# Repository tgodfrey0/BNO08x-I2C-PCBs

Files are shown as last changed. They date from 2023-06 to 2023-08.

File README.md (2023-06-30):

# BNO085 Interface Boards (I2C)

This repository contains W.I.P. code and hardware designed for a 9DOF sensor module using a BNO085.

The [`hardware` folder](hardware/README.md) contains all KiCAD files for the board.

The [`firmware` folder](firmware/README.md) contains the files required to run the sensor.

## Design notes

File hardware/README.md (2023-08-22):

# Hardware

The PCB designs were created in KiCAD and the panels were made using KiKit.

The sensor board is designed to be as small as possible, for this reason some features of the BNO085 are no longer accessible.

## PCB Board Key

Some of the boards are keyed to give them a known orientation. 

Both keys was created from the insersection between the main PCB edge circle and another circle placed in the top right corner of the main circle's bounding box. They are outlined below in the relevant screenshots (the y-axis has been inverted in Geogebra to visually match the KiCAD coordinate system).

### v6

All v6 boards have the same key and same key location. This is a through-hole with a diameter of 1mm. The centre of the key hole is located in the top left corner of the board; -3.35mm from the centre of the board along the x-axis, -3.25mm from the centre of the board along the y-axis. For both board sizes the hole is located in the same place. (Remember the KiCAD y-axis is inverted, therefore the delta-y of -3.25 means the hole is above the centre of the board.) 

### v5

The v5 board design has no physical key, however orientation pads were added to the front and back silkscreen these are in the top-left, top-right and bottom-right corners and can be used to orientate the board.

### v3

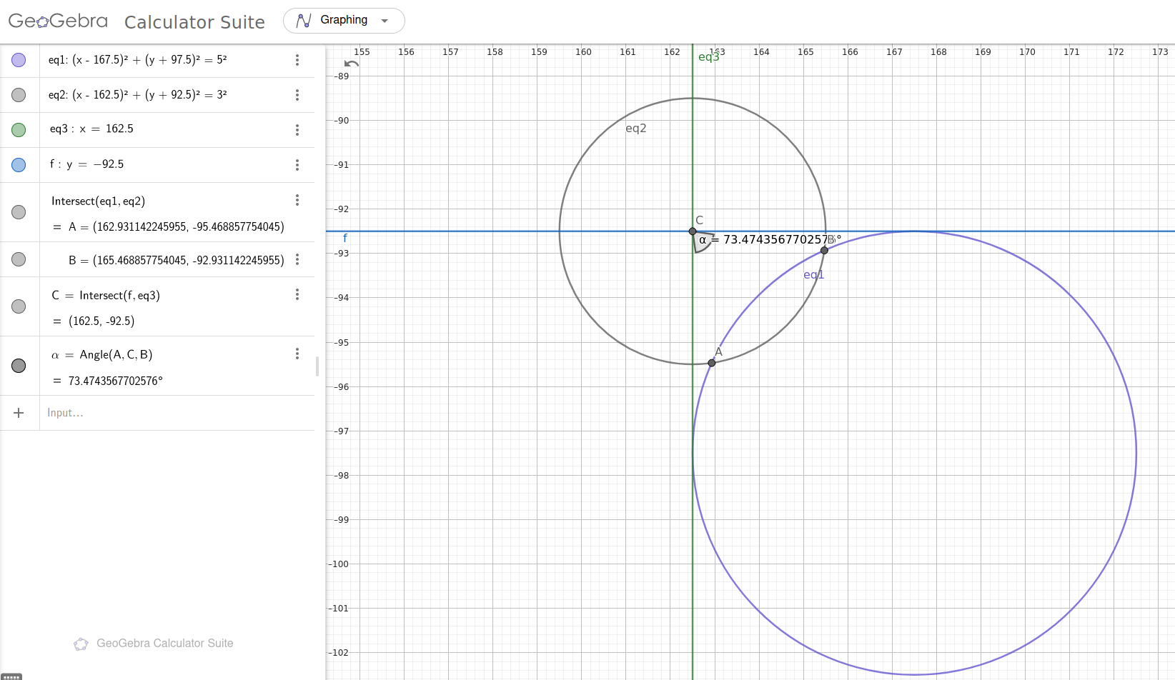
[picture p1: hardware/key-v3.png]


### v3-base

This board is the base for the `v3` panel. The difference is the flat spots by each pin to allow it to be panelised. This means the dimensions are slightly different.

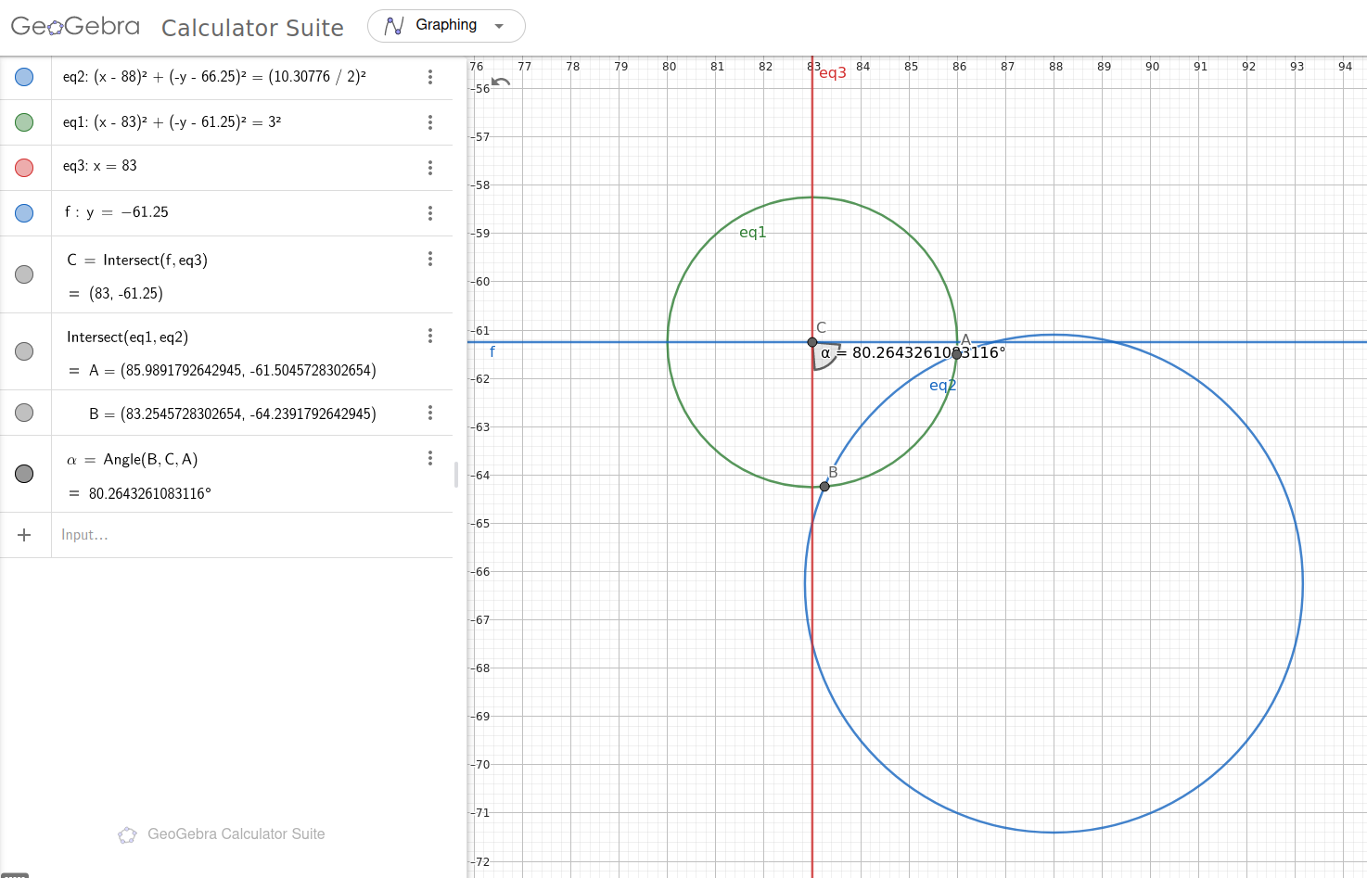
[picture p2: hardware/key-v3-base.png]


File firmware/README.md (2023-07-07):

# Firmware

The `adafruit-testing` folder contains very crude code used for I2C communication with an [Adafruit BNO085 breakout board](https://www.adafruit.com/product/4754#technical-details). This code is **not** intended to be used for project with the breakout board, it was used to check the minimum number of pins needed to communicate with the BNO085.

The `bno085-firmware` submodule contains the production code for the sensor. More info can be found [here](https://github.com/tgodfrey0/bno085-i2c-firmware).

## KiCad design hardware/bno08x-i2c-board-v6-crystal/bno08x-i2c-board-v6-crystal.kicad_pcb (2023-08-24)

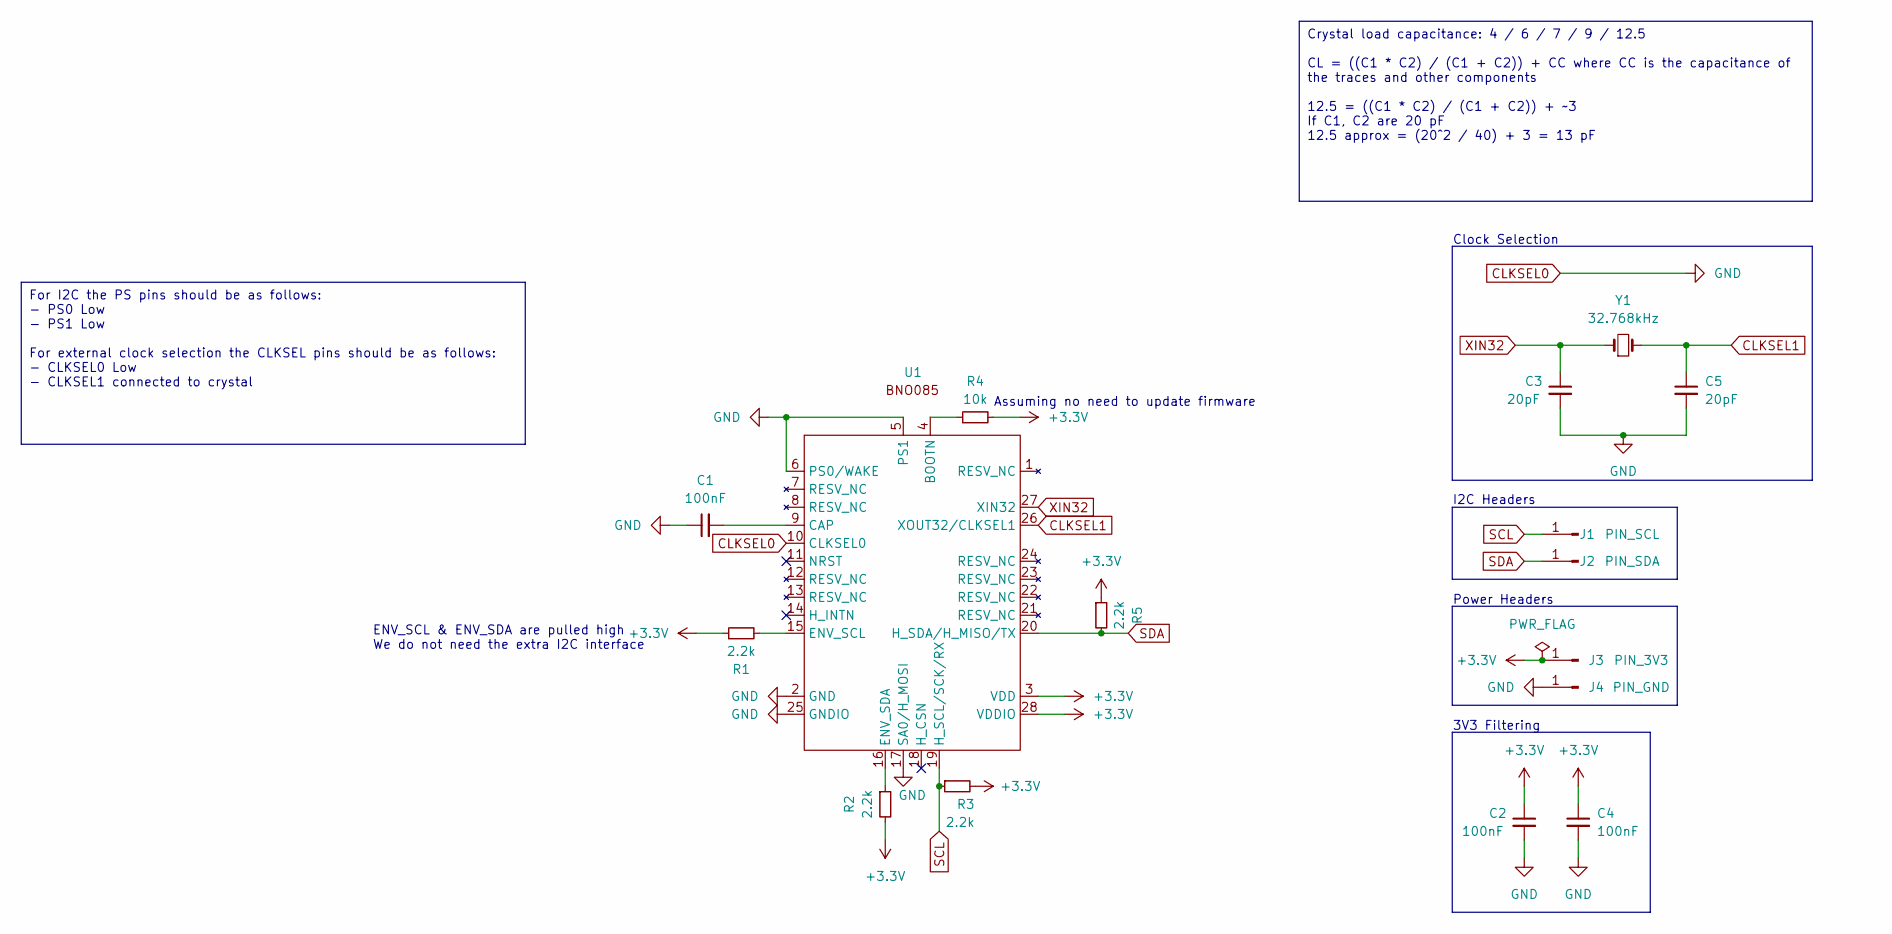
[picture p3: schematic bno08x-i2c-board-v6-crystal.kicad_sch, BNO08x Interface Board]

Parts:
C1, C2, C4: 100nF; C_0402_1005Metric
C3, C5: 20pF; C_0402_1005Metric
J1: PIN_SCL; PinHeader_1x01_P1.00mm_Vertical
J2: PIN_SDA; PinHeader_1x01_P1.00mm_Vertical
J3: PIN_3V3; PinHeader_1x01_P1.00mm_Vertical
J4: PIN_GND; PinHeader_1x01_P1.00mm_Vertical
R1, R2, R3, R5: 2.2k; R_0402_1005Metric
R4: 10k; R_0402_1005Metric
U1: LGA-28_5.2x3.8mm_P0.5mm
Y1: 32.768kHz; Crystal_SMD_MicroCrystal_CM9V-T1A-2Pin_1.6x1.0mm

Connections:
+3.3V: C2.1, C4.1, J3.1, R1.1, R2.2, R3.2, R4.2, R5.1, U1.3 (VDD), U1.28 (VDDIO)
CLKSEL0: C1.1, C2.2, C3.2, C4.2, C5.2, J4.1, U1.2 (GND), U1.5 (PS1), U1.6 (PS0/WAKE), U1.10 (CLKSEL0), U1.17 (SA0/H_MOSI), U1.25 (GNDIO)
CLKSEL1: C5.1, U1.26 (XOUT32/CLKSEL1), Y1.2
unnamed: R4.1, U1.4 (BOOTN)
unnamed: C1.2, U1.9 (CAP)
unnamed: R1.2, U1.15 (ENV_SCL)
unnamed: R2.1, U1.16 (ENV_SDA)
SCL: J1.1, R3.1, U1.19 (H_SCL/SCK/RX)
SDA: J2.1, R5.2, U1.20 (H_SDA/H_MISO/TX)
XIN32: C3.1, U1.27 (XIN32), Y1.1

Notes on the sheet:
Crystal load capacitance: 4 / 6 / 7 / 9 / 12.5 CL = ((C1 * C2) / (C1 + C2)) + CC where CC is the capacitance of the traces and other components 12.5 = ((C1 * C2) / (C1 + C2)) + ~3 If C1, C2 are 20 pF 12.5 approx = (20^2 / 40) + 3 = 13 pF
For I2C the PS pins should be as follows: - PS0 Low - PS1 Low For external clock selection the CLKSEL pins should be as follows: - CLKSEL0 Low - CLKSEL1 connected to crystal
3V3 Filtering
Assuming no need to update firmware
Clock Selection
I2C Headers
ENV_SCL & ENV_SDA are pulled high We do not need the extra I2C interface
Power Headers

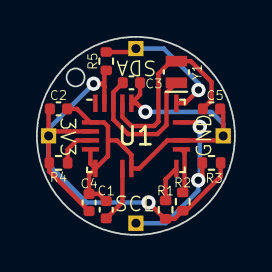
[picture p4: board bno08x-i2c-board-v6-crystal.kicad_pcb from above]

Board: 2 copper layers, 11.0 x 11.0 mm, 16 parts (0 on the bottom side), 10 nets.

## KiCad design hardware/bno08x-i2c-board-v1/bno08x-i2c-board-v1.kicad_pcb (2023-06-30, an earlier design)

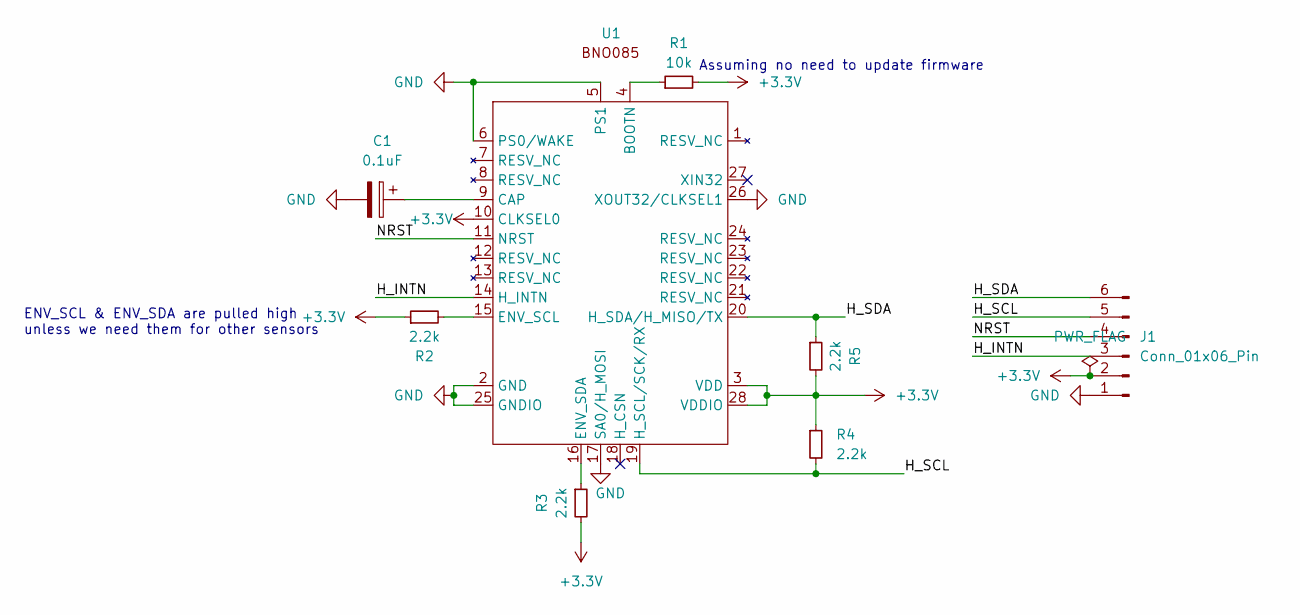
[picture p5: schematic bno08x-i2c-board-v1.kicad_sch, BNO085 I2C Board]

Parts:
C1: 0.1uF; CP_Elec_4x3.9
J1: Conn_01x06_Pin; PinHeader_1x06_P2.54mm_Horizontal
R1: 10k; R_0805_2012Metric
R2, R3, R4, R5: 2.2k; R_0805_2012Metric
U1: LGA-28_5.2x3.8mm_P0.5mm

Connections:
+3.3V: J1.2, R1.2, R2.1, R3.2, R4.1, R5.2, U1.3 (VDD), U1.10 (CLKSEL0), U1.28 (VDDIO)
/H_INTN: J1.3, U1.14 (H_INTN)
/H_SCL: J1.5, R4.2, U1.19 (H_SCL/SCK/RX)
/H_SDA: J1.6, R5.1, U1.20 (H_SDA/H_MISO/TX)
/NRST: J1.4, U1.11 (NRST)
GND: C1.2, J1.1, U1.2 (GND), U1.5 (PS1), U1.6 (PS0/WAKE), U1.17 (SA0/H_MOSI), U1.25 (GNDIO), U1.26 (XOUT32/CLKSEL1)
unnamed: R1.1, U1.4 (BOOTN)
unnamed: C1.1, U1.9 (CAP)
unnamed: R2.2, U1.15 (ENV_SCL)
unnamed: R3.1, U1.16 (ENV_SDA)

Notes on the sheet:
Assuming no need to update firmware
ENV_SCL & ENV_SDA are pulled high unless we need them for other sensors

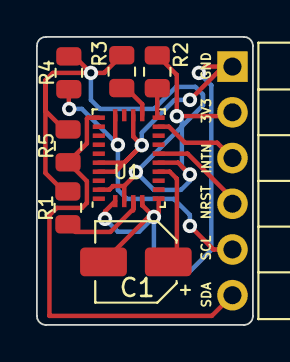
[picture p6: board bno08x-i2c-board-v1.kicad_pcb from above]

Board: 2 copper layers, 12.0 x 16.0 mm, 8 parts (0 on the bottom side), 10 nets.

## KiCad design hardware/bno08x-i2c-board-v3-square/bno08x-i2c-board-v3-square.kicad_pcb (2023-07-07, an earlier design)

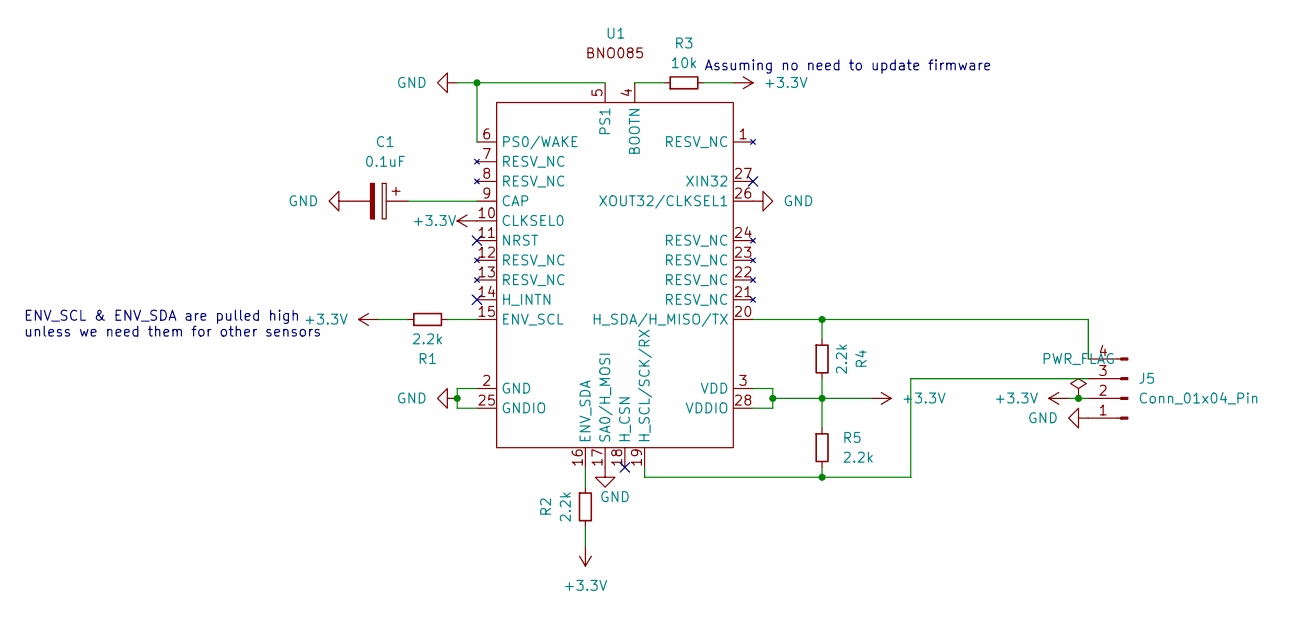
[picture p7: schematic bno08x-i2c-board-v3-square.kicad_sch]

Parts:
C1: 0.1uF; C_0402_1005Metric
J5: Conn_01x04_Pin; PinHeader_1x04_P1.00mm_Vertical
R1, R2, R4, R5: 2.2k; R_0402_1005Metric
R3: 10k; R_0402_1005Metric
U1: LGA-28_5.2x3.8mm_P0.5mm

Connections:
+3.3V: J5.2, R1.1, R2.2, R3.2, R4.2, R5.1, U1.3 (VDD), U1.10 (CLKSEL0), U1.28 (VDDIO)
GND: C1.2, J5.1, U1.2 (GND), U1.5 (PS1), U1.6 (PS0/WAKE), U1.17 (SA0/H_MOSI), U1.25 (GNDIO), U1.26 (XOUT32/CLKSEL1)
unnamed: J5.3, R5.2, U1.19 (H_SCL/SCK/RX)
unnamed: J5.4, R4.1, U1.20 (H_SDA/H_MISO/TX)
unnamed: R3.1, U1.4 (BOOTN)
unnamed: C1.1, U1.9 (CAP)
unnamed: R1.2, U1.15 (ENV_SCL)
unnamed: R2.1, U1.16 (ENV_SDA)

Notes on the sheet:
Assuming no need to update firmware
ENV_SCL & ENV_SDA are pulled high unless we need them for other sensors

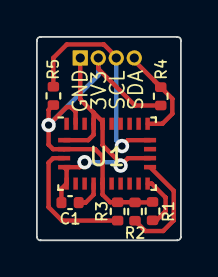
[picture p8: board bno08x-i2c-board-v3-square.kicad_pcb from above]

Board: 2 copper layers, 8.0 x 11.3 mm, 8 parts (0 on the bottom side), 8 nets.

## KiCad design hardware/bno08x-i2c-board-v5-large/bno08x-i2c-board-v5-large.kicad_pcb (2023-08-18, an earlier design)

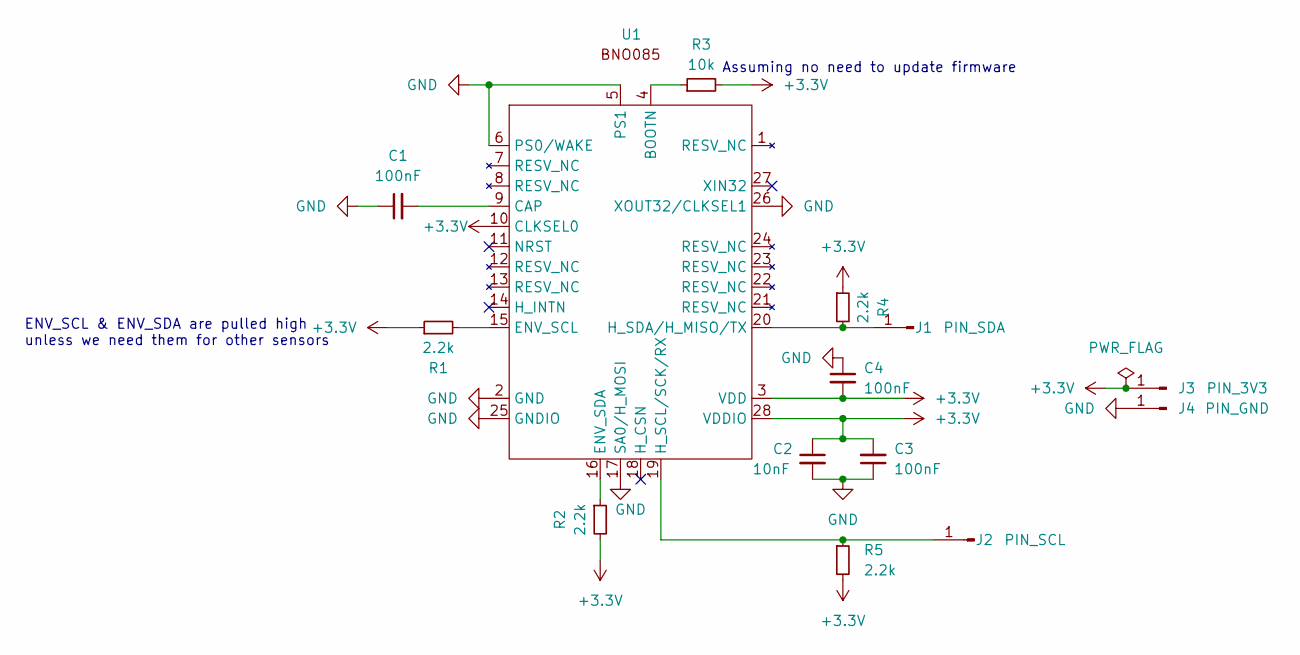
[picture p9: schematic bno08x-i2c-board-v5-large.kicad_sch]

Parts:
C1, C3, C4: 100nF; C_0402_1005Metric
C2: 10nF; C_0402_1005Metric
J1: PIN_SDA; PinHeader_1x01_P1.00mm_Vertical
J2: PIN_SCL; PinHeader_1x01_P1.00mm_Vertical
J3: PIN_3V3; PinHeader_1x01_P1.00mm_Vertical
J4: PIN_GND; PinHeader_1x01_P1.00mm_Vertical
R1, R2, R4, R5: 2.2k; R_0402_1005Metric
R3: 10k; R_0402_1005Metric
U1: LGA-28_5.2x3.8mm_P0.5mm

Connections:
+3.3V: C2.1, C3.2, C4.2, J3.1, R1.1, R2.2, R3.2, R4.1, R5.2, U1.3 (VDD), U1.10 (CLKSEL0), U1.28 (VDDIO)
GND: C1.1, C2.2, C3.1, C4.1, J4.1, U1.2 (GND), U1.5 (PS1), U1.6 (PS0/WAKE), U1.17 (SA0/H_MOSI), U1.25 (GNDIO), U1.26 (XOUT32/CLKSEL1)
unnamed: J1.1, R4.2, U1.20 (H_SDA/H_MISO/TX)
unnamed: J2.1, R5.1, U1.19 (H_SCL/SCK/RX)
unnamed: R3.1, U1.4 (BOOTN)
unnamed: C1.2, U1.9 (CAP)
unnamed: R1.2, U1.15 (ENV_SCL)
unnamed: R2.1, U1.16 (ENV_SDA)

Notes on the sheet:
Assuming no need to update firmware
ENV_SCL & ENV_SDA are pulled high unless we need them for other sensors

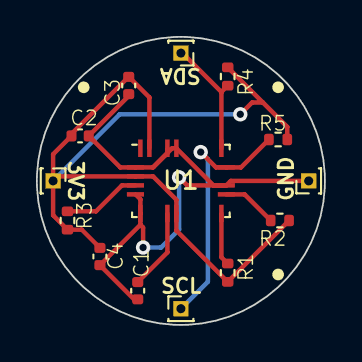
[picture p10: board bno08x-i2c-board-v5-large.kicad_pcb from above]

Board: 2 copper layers, 16.0 x 16.0 mm, 14 parts (0 on the bottom side), 8 nets.

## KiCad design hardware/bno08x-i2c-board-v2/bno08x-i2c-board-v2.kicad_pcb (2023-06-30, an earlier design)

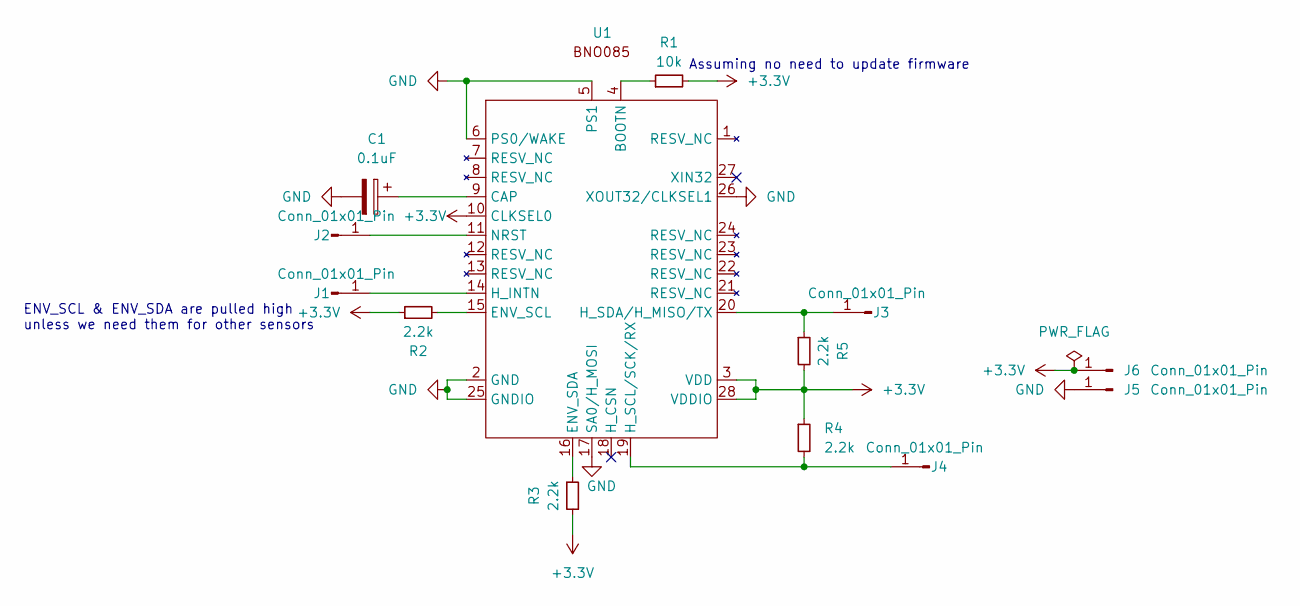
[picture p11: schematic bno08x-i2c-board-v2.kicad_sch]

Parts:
C1: 0.1uF; C_0402_1005Metric
J1, J2, J3, J4, J5, J6: Conn_01x01_Pin; PinHeader_1x01_P1.00mm_Vertical
R1: 10k; R_0402_1005Metric
R2, R3, R4, R5: 2.2k; R_0402_1005Metric
U1: LGA-28_5.2x3.8mm_P0.5mm

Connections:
+3.3V: J6.1, R1.2, R2.1, R3.2, R4.1, R5.2, U1.3 (VDD), U1.10 (CLKSEL0), U1.28 (VDDIO)
GND: C1.2, J5.1, U1.2 (GND), U1.5 (PS1), U1.6 (PS0/WAKE), U1.17 (SA0/H_MOSI), U1.25 (GNDIO), U1.26 (XOUT32/CLKSEL1)
unnamed: J1.1, U1.14 (H_INTN)
unnamed: J2.1, U1.11 (NRST)
unnamed: J3.1, R5.1, U1.20 (H_SDA/H_MISO/TX)
unnamed: J4.1, R4.2, U1.19 (H_SCL/SCK/RX)
unnamed: R1.1, U1.4 (BOOTN)
unnamed: C1.1, U1.9 (CAP)
unnamed: R2.2, U1.15 (ENV_SCL)
unnamed: R3.1, U1.16 (ENV_SDA)

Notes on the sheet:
Assuming no need to update firmware
ENV_SCL & ENV_SDA are pulled high unless we need them for other sensors

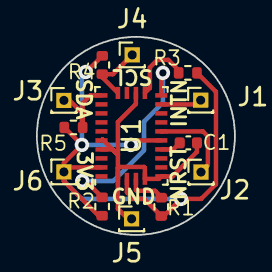
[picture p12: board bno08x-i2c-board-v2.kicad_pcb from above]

Board: 2 copper layers, 11.0 x 11.0 mm, 13 parts (0 on the bottom side), 10 nets.

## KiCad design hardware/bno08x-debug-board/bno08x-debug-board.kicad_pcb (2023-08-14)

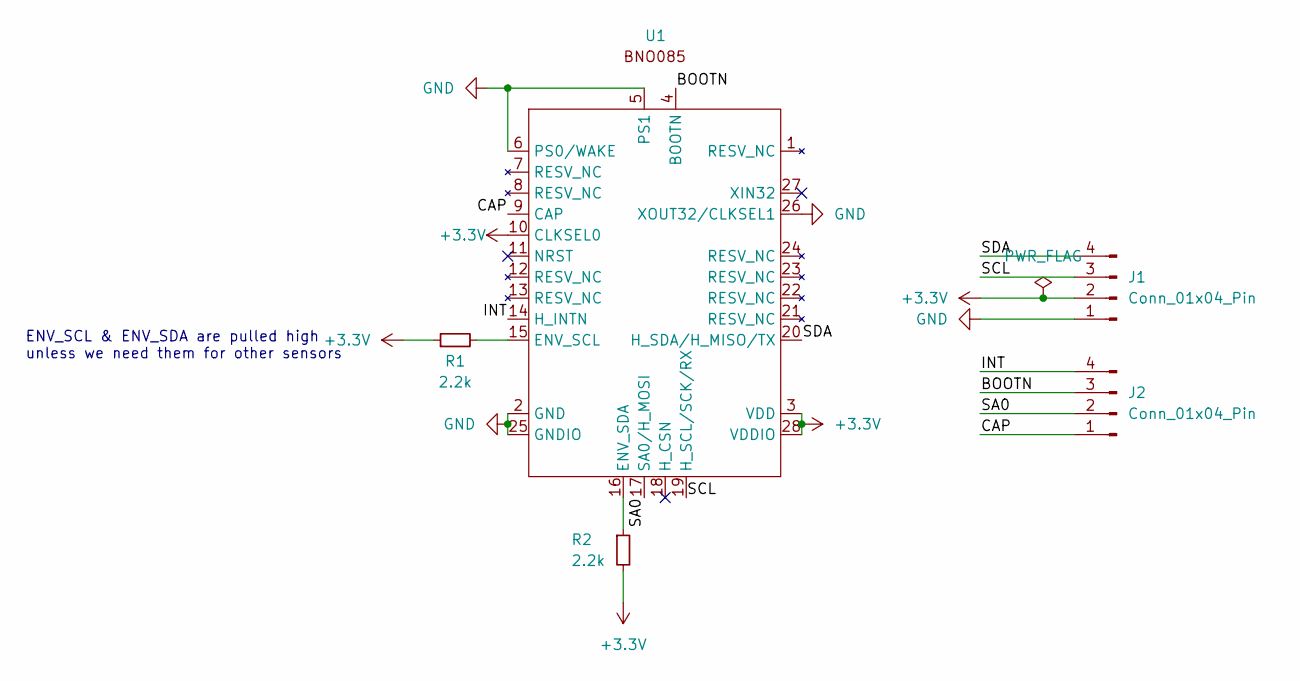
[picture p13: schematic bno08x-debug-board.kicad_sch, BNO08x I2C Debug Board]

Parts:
J1, J2: Conn_01x04_Pin; PinHeader_1x04_P2.54mm_Vertical
R1, R2: 2.2k; R_Axial_DIN0309_L9.0mm_D3.2mm_P12.70mm_Horizontal
U1: LGA-28_5.2x3.8mm_P0.5mm

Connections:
+3.3V: J1.2, R1.1, R2.2, U1.3 (VDD), U1.10 (CLKSEL0), U1.28 (VDDIO)
/BOOTN: J2.3, U1.4 (BOOTN)
/CAP: J2.1, U1.9 (CAP)
/INT: J2.4, U1.14 (H_INTN)
/SA0: J2.2, U1.17 (SA0/H_MOSI)
/SCL: J1.3, U1.19 (H_SCL/SCK/RX)
/SDA: J1.4, U1.20 (H_SDA/H_MISO/TX)
GND: J1.1, U1.2 (GND), U1.5 (PS1), U1.6 (PS0/WAKE), U1.25 (GNDIO), U1.26 (XOUT32/CLKSEL1)
unnamed: R1.2, U1.15 (ENV_SCL)
unnamed: R2.1, U1.16 (ENV_SDA)

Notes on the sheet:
ENV_SCL & ENV_SDA are pulled high unless we need them for other sensors

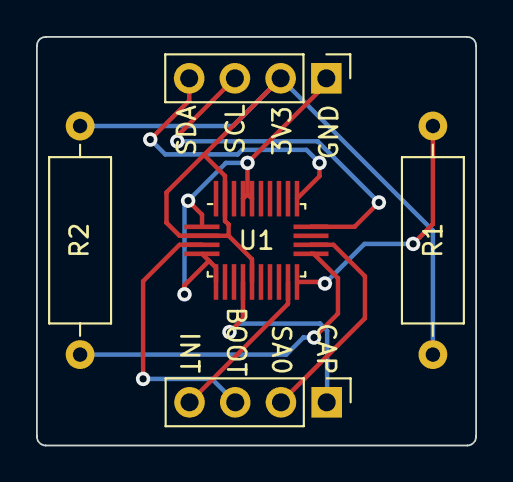
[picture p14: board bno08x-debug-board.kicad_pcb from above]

Board: 2 copper layers, 24.4 x 22.7 mm, 5 parts (0 on the bottom side), 10 nets.

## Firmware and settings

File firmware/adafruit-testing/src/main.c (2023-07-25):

/***********************************************************************************
 * @file   main.c
 * @author Toby Godfrey
 * @brief  I2C communication implementation for a Pico and Adafruit BNO085 board
 **********************************************************************************/

#include <stdbool.h>
#include <stddef.h>
#include <stdint.h>
#include <stdio.h>
#include <stdlib.h>
#include <string.h>
#include <inttypes.h>

#include "boards/pico.h"
#include "hardware/gpio.h"
#include "hardware/timer.h"
#include "pico/platform.h"
#include "pico/stdio.h"
#include "pico/stdlib.h"
#include "hardware/i2c.h"

#include "defs.h"
#include "pico/time.h"
#include "pico/types.h"

uint8_t payload[MAX_PAYLOAD_SIZE] = {0};
uint16_t inner_cargo_size = 0;

/*************************
 * Byte | Value
 *   0  | LSB Length
 *   1  | MSB Length
 *   2  | Channel
 *   3  | Sequence Number
 *   4+ | Data
 ************************/

uint8_t get_seq_num(){
  static uint8_t seq_num;
  uint8_t sn = seq_num;
  seq_num++;
  return sn;
}

/**
 * Endless loop with flashing the on-board LED
 *
 * @param[in] t_on     The time the LED is on for
 * @param[in] t_off    The time the LED is off for
 */
void flash_led_inf(uint64_t t_on, uint64_t t_off){
  for(;;){
    gpio_put(PICO_DEFAULT_LED_PIN, 1);
    sleep_ms(t_on);
    gpio_put(PICO_DEFAULT_LED_PIN, 0);
    sleep_ms(t_off);
  }
}


/**
 * Bounded loop with flashing the on-board LED
 *
 * @param[in] t_on     The time the LED is on for
 * @param[in] t_off    The time the LED is off for
 * @param[in] n        The number of iterations
 */
void flash_led_n(uint64_t t_on, uint64_t t_off, uint16_t n){
  for(uint16_t i = 0; i < n; i++){
    gpio_put(PICO_DEFAULT_LED_PIN, 1);
    sleep_ms(t_on);
    gpio_put(PICO_DEFAULT_LED_PIN, 0);
    sleep_ms(t_off);
  }
}

/**
 * Create the absolute time struct for the specified timeout
 */
absolute_time_t calc_timeout(){
  absolute_time_t abs_time_limit = {(time_us_64() + (TIMEOUT_MS * 1000))};
  return abs_time_limit;
}

unsigned int write_sensor(uint8_t* msg, uint16_t len){
  return i2c_write_blocking_until(I2C_INST, BNO085_ADDR, msg, len, false, calc_timeout());
}

/**
 * Initialise the I2C functionality and LED
 */
void init_pins(){

  gpio_init(PICO_DEFAULT_LED_PIN);
  gpio_set_dir(PICO_DEFAULT_LED_PIN, GPIO_OUT);
  gpio_pull_down(PICO_DEFAULT_LED_PIN);

  printf("Status LED successfully configured\n");

  flash_led_n(500, 500, 3);

#if !defined(I2C_INST) || !defined(SDA_PIN) || !defined(SCL_PIN)
  #warning No I2C pins are set
  puts("I2C pins were not defined")
#else

  i2c_init(I2C_INST, BAUD_RATE_HZ);

  gpio_set_function(SDA_PIN, GPIO_FUNC_I2C);
  gpio_set_function(SCL_PIN, GPIO_FUNC_I2C);

  gpio_pull_up(SCL_PIN);
  gpio_pull_up(SDA_PIN);

  printf("I2C interface successfully configured\n");

#endif
}

/**
 * Open the I2C channel
 */
void open_channel(){
  /*
   *  Byte  | Value
   *   0,1  | Length = 5
   *   2    | Channel = 1 (Executable)
   *   3    | Sequence Number = 0
   *   4    | Payload = CMD 2 (On)
   */
  uint8_t pkt[] = {5, 0, 1, get_seq_num(), 2};

  bool succ = false;
  for(uint8_t attempts; attempts < MAX_ATTEMPTS; attempts++){
    if(write_sensor(pkt, sizeof(pkt)) != PICO_ERROR_GENERIC){
      succ = true;
      break;
    }
    sleep_ms(100);
  }

  if(!succ){
    printf("Failed to open channel to sensor\n");
    flash_led_inf(1000, 1000);
  }

  sleep_ms(300);
}

/**
 * Format the received payload into the accelerometer struct
 *
 * @param[in] sensor_reports    The full sensor struct
 */
void format_accelerometer_data(struct full_sensor_reports* sensor_reports){
  printf("Accelerometer data:\n");
  printf("Status: %d\n", sensor_reports->accelerometer->input_report->accelerometer_input_report->status);
  printf("Delay: %d\n", sensor_reports->accelerometer->input_report->accelerometer_input_report->delay);
  printf("(x, y, z) m/s^2: (%f, %f, %f) m/s^2\n", sensor_reports->accelerometer->input_report->accelerometer_input_report->x, sensor_reports->accelerometer->input_report->accelerometer_input_report->y, sensor_reports->accelerometer->input_report->accelerometer_input_report->z);
}

/**
 * Format the received payload into the gyroscope struct
 *
 * @param[in] sensor_reports    The full sensor struct
 */
void format_gyroscope_data(struct full_sensor_reports* sensor_reports){
  printf("Gyroscope data:\n");
  printf("Status: %d\n", sensor_reports->gyroscope->input_report->gyroscope_input_report->status);
  printf("Delay: %d\n", sensor_reports->gyroscope->input_report->gyroscope_input_report->delay);
  printf("(x, y, z) rad/s: (%f, %f, %f) rad/s\n", sensor_reports->gyroscope->input_report->gyroscope_input_report->x, sensor_reports->gyroscope->input_report->gyroscope_input_report->y, sensor_reports->gyroscope->input_report->gyroscope_input_report->z);
}

/**
 * Format the received payload into the magnetic field struct
 *
 * @param[in] sensor_reports    The full sensor struct
 */
void format_magnetic_field_data(struct full_sensor_reports* sensor_reports){
  printf("Magnetic field sensor data:\n");
  printf("Status: %d\n", sensor_reports->magnetic_field->input_report->magnetic_field_input_report->status);
  printf("Delay: %d\n", sensor_reports->magnetic_field->input_report->magnetic_field_input_report->delay);
  printf("(x, y, z) uT: (%f, %f, %f) uT\n", sensor_reports->magnetic_field->input_report->magnetic_field_input_report->x, sensor_reports->magnetic_field->input_report->magnetic_field_input_report->y, sensor_reports->magnetic_field->input_report->magnetic_field_input_report->z);
}

/**
 * Print the reports received
 *
 * @param[in] sensor_reports    The full sensor struct
 */
void output_reports(struct full_sensor_reports* sensor_reports){
  static uint16_t report_count = 0;

  if(sensor_reports->accelerometer->enabled) format_accelerometer_data(sensor_reports);
  if(sensor_reports->magnetic_field->enabled) format_magnetic_field_data(sensor_reports);
  if(sensor_reports->gyroscope->enabled) format_gyroscope_data(sensor_reports);

  if(sensor_reports->accelerometer->enabled || sensor_reports->magnetic_field->enabled || sensor_reports->gyroscope->enabled){
    printf("\n");
    report_count++;
  }
}

/**
 * Parse the received payload into the accelerometer struct
 *
 * @param[out] sensor_report    The full sensor struct
 * @param[in] cargo_ptr A pointer to the start of the cargo in the payload buffer
 */
void parse_accelerometer_data(struct full_sensor_reports* sensor_reports, uint8_t* cargo_ptr){
  if(inner_cargo_size != 10){
    printf("Invalid report from accelerometer\n");
    return;
  }

  int16_t x = (*(cargo_ptr + 4) | (*(cargo_ptr + 5) << 8)) * scale_q(8);
  int16_t y = (*(cargo_ptr + 6) | (*(cargo_ptr + 7) << 8)) * scale_q(8);
  int16_t z = (*(cargo_ptr + 8) | (*(cargo_ptr + 9) << 8)) * scale_q(8);

  sensor_reports->accelerometer->input_report->accelerometer_input_report->status = *(cargo_ptr + 2);
  sensor_reports->accelerometer->input_report->accelerometer_input_report->delay = *(cargo_ptr + 3);
  sensor_reports->accelerometer->input_report->accelerometer_input_report->x = x;
  sensor_reports->accelerometer->input_report->accelerometer_input_report->y = y;
  sensor_reports->accelerometer->input_report->accelerometer_input_report->z = z;
}

/**
 * Parse the received payload into the gyroscope struct
 *
 * @param[out] sensor_report    The full sensor struct
 * @param[in] cargo_ptr A pointer to the start of the cargo in the payload buffer
 */
void parse_gyroscope_data(struct full_sensor_reports* sensor_reports, uint8_t* cargo_ptr){
  if(inner_cargo_size != 10){
    printf("Invalid report from gyroscope\n");
    return;
  }

  int16_t x = (*(cargo_ptr + 4) | (*(cargo_ptr + 5) << 8)) * scale_q(9);
  int16_t y = (*(cargo_ptr + 6) | (*(cargo_ptr + 7) << 8)) * scale_q(9);
  int16_t z = (*(cargo_ptr + 8) | (*(cargo_ptr + 9) << 8)) * scale_q(9);

  sensor_reports->gyroscope->input_report->gyroscope_input_report->status = *(cargo_ptr + 2);
  sensor_reports->gyroscope->input_report->gyroscope_input_report->delay = *(cargo_ptr + 3);
  sensor_reports->gyroscope->input_report->gyroscope_input_report->x = x;
  sensor_reports->gyroscope->input_report->gyroscope_input_report->y = y;
  sensor_reports->gyroscope->input_report->gyroscope_input_report->z = z;
}

/**
 * Parse the received payload into the magnetic field struct
 *
 * @param[out] sensor_report    The full sensor struct
 * @param[in] cargo_ptr         A pointer to the start of the cargo in the payload buffer
 */
void parse_magnetic_field_data(struct full_sensor_reports* sensor_reports, uint8_t* cargo_ptr){
  if(inner_cargo_size != 10){
    printf("Invalid report from magnetic field sensor\n");
    return;
  }

  int16_t x = (*(cargo_ptr + 4) | (*(cargo_ptr + 5) << 8)) * scale_q(4);
  int16_t y = (*(cargo_ptr + 6) | (*(cargo_ptr + 7) << 8)) * scale_q(4);
  int16_t z = (*(cargo_ptr + 8) | (*(cargo_ptr + 9) << 8)) * scale_q(4);

  sensor_reports->magnetic_field->input_report->magnetic_field_input_report->status = *(cargo_ptr + 2);
  sensor_reports->magnetic_field->input_report->magnetic_field_input_report->delay = *(cargo_ptr + 3);
  sensor_reports->magnetic_field->input_report->magnetic_field_input_report->x = x;
  sensor_reports->magnetic_field->input_report->magnetic_field_input_report->y = y;
  sensor_reports->magnetic_field->input_report->magnetic_field_input_report->z = z;
}

/**
 * Convert the payload buffer into useful data
 *
 * @param[out] sensor_reports   The full sensor struct
 */
void parse_payload(struct full_sensor_reports* sensor_reports){
  uint8_t* cargo_ptr = &(payload[9]); // First 9 bytes are the header and timebase references
  switch (payload[9]) {     
    case ACCELEROMETER_ID:
      parse_accelerometer_data(sensor_reports, cargo_ptr);
      break;
    case GYROSCOPE_CALIBRATED_ID:
      parse_gyroscope_data(sensor_reports, cargo_ptr);
      break;
    case MAGNET_FIELD_CALIBRATED_ID:
      parse_magnetic_field_data(sensor_reports, cargo_ptr);
      break;
  }
}

/**
 * Read the header and then the payload data for a given channel
 *
 * @param[out] sensor_reports   The full sensor struct
 * @param[out] buf              A struct pointer to store the output
 */
void read_sensor(struct full_sensor_reports* sensor_reports, struct single_sensor_reports* buf){
  buf->size = 0;

  uint8_t header[4];
  uint8_t* payload_ptr = payload;

  uint8_t res = i2c_read_blocking_until(I2C_INST, BNO085_ADDR, header, 4, false, calc_timeout());

  if(res == PICO_ERROR_GENERIC){
    printf("Failed to read header\n");
    flash_led_inf(2000, 2000);
  } else if(res == PICO_ERROR_TIMEOUT){
    printf("Timeout reached whilst reading header\n");
    flash_led_inf(5000, 5000);
  }

  uint16_t payload_size = (uint16_t)header[0] | (uint16_t)header[1] << 8;
  // Remove continuation bit
  payload_size &= ~0x8000;

  if(payload_size > MAX_PAYLOAD_SIZE){
    printf("Payload too large for buffer\n");
    flash_led_inf(3000, 3000);
  }

  uint16_t bytes_remaining = payload_size;
  uint16_t read_size;
  uint8_t i2c_buf[MAX_PAYLOAD_SIZE];
  uint16_t payload_read_amount = 0;
  bool first_read = true;

  while(bytes_remaining > 0){
    if(first_read) read_size = min(MAX_PAYLOAD_SIZE, (size_t)bytes_remaining);
    else read_size = min(MAX_PAYLOAD_SIZE, (size_t)(bytes_remaining + 4));

    res = i2c_read_blocking(I2C_INST, BNO085_ADDR, i2c_buf, read_size, false);

    if(first_read){
      payload_read_amount = read_size;
      memcpy(payload_ptr, i2c_buf, payload_read_amount);
      first_read = false;
    } else {
      payload_read_amount = read_size - 4;
      memcpy(payload_ptr, i2c_buf, payload_read_amount);
    }

    payload_ptr += payload_read_amount;
    bytes_remaining -= payload_read_amount;
  }

  if(payload_size == 65535) { // 65535 indicates an error
    printf("Error returned from sensor\n");
    flash_led_inf(4000, 4000);
  }


  buf->size = payload_size;

  if(payload_size > 0) {
    inner_cargo_size = payload_size - HEADER_TIMEBASE_OFFSET;
    parse_payload(sensor_reports);
  }

  memset(payload, 0, payload_size);
}

/**
 * Read all three sensor channels
 *
 * @param[in] sensor_reports    The struct with all sensor data
 */
void read_all_sensors(struct full_sensor_reports* sensor_reports){
  read_sensor(sensor_reports, sensor_reports->accelerometer);
  read_sensor(sensor_reports, sensor_reports->magnetic_field);
  read_sensor(sensor_reports, sensor_reports->gyroscope);
}

/**
 * Polls the sensor over I2C and process any output
 *
 * @param[in] sensor_reports    The struct with all sensor data
 */
void poll_sensor(struct full_sensor_reports* sensor_reports){
  read_all_sensors(sensor_reports);

  output_reports(sensor_reports);

  sleep_ms(SAMPLE_DELAY_MS);
}

/**
 * Send a Set Feature packet to enable the given sensor
 *
 * @param sensor    The struct for the sensor to enable
 */
void enable_sensor(struct single_sensor_reports* sensor){
  uint8_t period[4];

  uint64_t period_us = SAMPLE_RATE_MS * 1000;

  period[0] = period_us & 0xFF;
  period[1] = (period_us >> 8) & 0xFF;
  period[2] = (period_us >> 16) & 0xFF;
  period[3] = (period_us >> 24) & 0xFF;

  uint8_t pkt[] = {
    0x15, // Length LSB
    0x00, // Length MSB
    0x02, // Channel
    get_seq_num(),
    0xFD, // Report ID
    sensor->sensor_id,
    0, // Feature flags
    0, // Change sensitivity LSB
    0, // Change sensitivity MSB
    period[0], // Report interval LSB
    period[1],
    period[2],
    period[3], // Report interval MSB
    0, // Batch interval LSB
    0,
    0,
    0, // Batch interval MSB
    0, // Sensor-specific configuration word LSB
    0,
    0,
    0  // Sensor-specific configuration word MSB
  };

  uint8_t res = write_sensor(pkt, sizeof(pkt));

  if(res == PICO_ERROR_GENERIC){
    printf("Failed to enable feature %x\n", sensor->sensor_id);
  } else if(res == PICO_ERROR_TIMEOUT){
    printf("Timeout reached when enabling feature %x\n", sensor->sensor_id);
  } else {
    printf("Successfully enabled feature 0x%x with a reporting period of %d ms\n", sensor->sensor_id, SAMPLE_RATE_MS);
    sensor->enabled = true;
  }
}

/**
 * Configures which sensors should run
 *
 * @param[in] sensor_reports    Full sensor struct
 */
void configure_sensors(struct full_sensor_reports* sensor_reports){
  printf("Enabling sensors\n");

  enable_sensor(sensor_reports->accelerometer);
  enable_sensor(sensor_reports->magnetic_field);
  enable_sensor(sensor_reports->gyroscope); 

  printf("Sensors enabled\n");
}

int main()
{
  stdio_init_all();

  struct accelerometer_input_report* acc_data = &(struct accelerometer_input_report){
    .status = 0,
    .delay = 0,
    .x = 0,
    .y = 0,
    .z = 0
  };

  struct magnetic_field_input_report* mag_data = &(struct magnetic_field_input_report){
    .status = 0,
    .delay = 0,
    .x = 0,
    .y = 0,
    .z = 0
  };

  struct gyroscope_calibrated_input_report* gyro_data = &(struct gyroscope_calibrated_input_report){
    .status = 0,
    .delay = 0,
    .x = 0,
    .y = 0,
    .z = 0
  };

  union input_report* acc_rep = &(union input_report){
    .accelerometer_input_report = acc_data
  };

  union input_report* mag_rep = &(union input_report){
    .magnetic_field_input_report = mag_data
  };

  union input_report* gyro_rep = &(union input_report){
    .gyroscope_input_report = gyro_data
  };

  struct single_sensor_reports* accelerometer = &(struct single_sensor_reports) {
    .chan = 3,
    .sensor_id = ACCELEROMETER_ID,
    .size = 0,
    .input_report = acc_rep,
    .enabled = false
  };

  struct single_sensor_reports* gyroscope_calibrated = &(struct single_sensor_reports) {
    .chan = 3,
    .sensor_id = GYROSCOPE_CALIBRATED_ID,
    .size = 0,
    .input_report = gyro_rep,
    .enabled = false
  };

  struct single_sensor_reports* magnetic_field = &(struct single_sensor_reports) {
    .chan = 3,
    .sensor_id = MAGNET_FIELD_CALIBRATED_ID,
    .size = 0,
    .input_report = mag_rep,
    .enabled = false
  };

  struct full_sensor_reports* sensor_reports = &(struct full_sensor_reports) {
    .accelerometer = accelerometer,
    .gyroscope = gyroscope_calibrated,
    .magnetic_field = magnetic_field
  };

  init_pins();

  open_channel();

  configure_sensors(sensor_reports);

  flash_led_n(100, 100, 5);

  for (;;) poll_sensor(sensor_reports);

  return 0;
}

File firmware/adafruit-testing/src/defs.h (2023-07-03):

/******************************************************************************
 * @file   defs.h
 * @author Toby Godfrey
 * @brief  Preprocessor definitions
 *****************************************************************************/

#pragma once

#include <stdbool.h>
#include <stdint.h>

#define scale_q(n) (1.0f / (1<<n))
#define min(a,b) ({ __typeof__ (a) _a = (a); __typeof__ (b) _b = (b); _a < _b ? _a : _b; })

#define BNO085_ADDR	0b1001010U
#define I2C_INST	i2c0
#define SDA_PIN		16
#define SCL_PIN		17
#define BAUD_RATE_HZ	400000 // Fast mode 400 kb/s
#define TIMEOUT_MS	10000

#define MAX_PAYLOAD_SIZE    512
#define MAX_ATTEMPTS	    5 // Max tries to open an I2C connection to the sensor
#define SAMPLE_DELAY_MS	    60 // Delay between reading the sensors
#define SAMPLE_RATE_MS	    60 // The rate at which sensors push data to the bus

#define HEADER_TIMEBASE_OFFSET	      9
#define ACCELEROMETER_ID	      0x01
#define GYROSCOPE_CALIBRATED_ID	      0x02
#define MAGNET_FIELD_CALIBRATED_ID    0x03

// These are not necessarily all the same so the union allows forward compatibility
struct accelerometer_input_report {
  uint8_t status;
  uint8_t delay;
  float x;
  float y;
  float z;
};

struct magnetic_field_input_report {
  uint8_t status;
  uint8_t delay;
  float x;
  float y;
  float z;
};

struct gyroscope_calibrated_input_report {
  uint8_t status;
  uint8_t delay;
  float x;
  float y;
  float z;
};

union input_report {
  struct accelerometer_input_report* accelerometer_input_report;
  struct magnetic_field_input_report* magnetic_field_input_report;
  struct gyroscope_calibrated_input_report* gyroscope_input_report;
};

struct single_sensor_reports {
  const uint8_t chan;
  const uint8_t sensor_id;
  union input_report* input_report;
  uint16_t size;
  bool enabled;
};

struct full_sensor_reports {
  struct single_sensor_reports *accelerometer;
  struct single_sensor_reports *gyroscope;
  struct single_sensor_reports *magnetic_field;
};

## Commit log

2023-06-22 started schematic
    [bno085-i2c-board.kicad_pcb, bno085-i2c-board.kicad_sch]
2023-06-22 more schematic
    [bno085-i2c-board.kicad_sch]
2023-06-22 added pwr flag
    [bno085-i2c-board.kicad_sch]
2023-06-22 more pcb
    [bno085-i2c-board.kicad_pcb]
2023-06-22 new pcb resistors
    [bno085-i2c-board.kicad_pcb, bno085-i2c-board.kicad_sch]
2023-06-23 new board
    [bno085-i2c-board-v2.kicad_pcb, bno085-i2c-board-v2.kicad_sch, bno085-i2c-board.kicad_pcb]
2023-06-23 round board
    [bno085-i2c-board-v2.kicad_pcb, bno085-i2c-board-v2.kicad_sch]
2023-06-26 i2c no work
2023-06-26 maybe bug gone? moved to timeout when reading header
    [defs.h, main.c]
2023-06-27 sensor struct
2023-06-27 4 pin board
    [bno085-i2c-board-v3.kicad_pcb, bno085-i2c-board-v3.kicad_sch]
2023-06-27 removed debug prints
2023-06-28 added key
    [bno085-i2c-board-v3.kicad_pcb]
2023-06-28 issue from payload -> structs and timing
    [defs.h, main.c]
2023-06-29 works for one sensor
2023-06-29 square board
    [bno085-i2c-board-v3-square.kicad_pcb, bno085-i2c-board-v3-square.kicad_sch]
2023-06-30 square panel
    [bno085-i2c-board-v3-panel-manual.kicad_pcb, bno085-i2c-board-v3-panel-manual.kicad_sch, bno085-i2c-board-v3-panel.kicad_pcb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]
2023-06-30 small panels
    [bno085-i2c-board-v3-panel-base.kicad_pcb, bno085-i2c-board-v3-panel.kicad_pcb]
2023-06-30 panels and board metadata
    [bno085-i2c-board-v2.kicad_pcb, bno085-i2c-board-v3-large-panel.kicad_pcb, bno085-i2c-board-v3-large.kicad_pcb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]
2023-07-03 testing stencil generation
    [bno085-i2c-board-v3-panel-EdgeCuts.dxf, bno085-i2c-board-v3-panel-PasteBottom.dxf, bno085-i2c-board-v3-panel-PasteTop.dxf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]
2023-07-04 removed stencils
    [bno085-i2c-board-v3-panel-EdgeCuts.dxf, bno085-i2c-board-v3-panel-PasteBottom.dxf, bno085-i2c-board-v3-panel-PasteTop.dxf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]
2023-07-07 jlc fab files
    [bno085-i2c-board-v3-large-B_Cu.gbl, bno085-i2c-board-v3-large-B_Mask.gbs, bno085-i2c-board-v3-large-B_Paste.gbp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]
2023-07-07 drill map files
    [bno085-i2c-board-v3-large-NPTH-drl_map.gbr, bno085-i2c-board-v3-large-PTH-drl_map.gbr, bno085-i2c-board-v3-large-panel-NPTH-drl_map.gbr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]
2023-07-07 moved v3
    [bno085-i2c-board-v3-panel-base-B_Cu.gbl, bno085-i2c-board-v3-panel-base-B_Mask.gbs, bno085-i2c-board-v3-panel-base-B_Paste.gbp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]
2023-08-14 debug board
    [bno085-debug-board-panel-B_Cu.gbr, bno085-debug-board-panel-B_Mask.gbr, bno085-debug-board-panel-B_Paste.gbr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]
2023-08-23 change cap size
    [bno08x-i2c-board-v6-large-crystal.kicad_sch]
2023-08-24 v6 crystal
    [bno08x-i2c-board-v6-crystal-panel.kicad_pcb, bno08x-i2c-board-v6-crystal.kicad_pcb, bno08x-i2c-board-v6-crystal.kicad_sch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]
